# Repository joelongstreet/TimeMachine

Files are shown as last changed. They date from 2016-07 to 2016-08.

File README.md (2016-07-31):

# The Time Machine

An interactive hologram display.

## Hardware
Soldering several ICs was extremely cumbersome and time consuming, so I elected to design and print my own circuit boards.

### Schematic 
schematic

### Board Layout
board layout

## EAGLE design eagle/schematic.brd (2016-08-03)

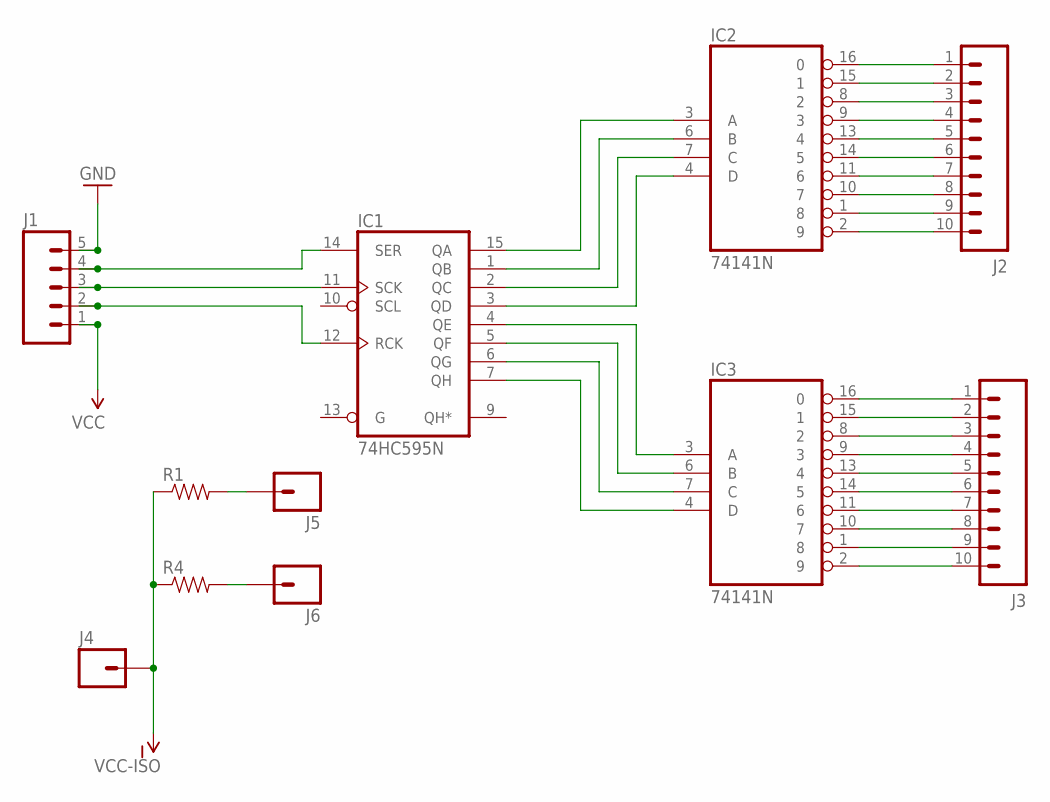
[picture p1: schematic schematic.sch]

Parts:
IC1: 74HC595N; DIL16
IC2, IC3: 74141N; DIL16
J1: M05LOCK; 1X05_LOCK
J2, J3: M10LOCK; 1X10_LOCK
J4, J5, J6: M01PTH; 1X01
R1, R4: RESISTORPTH-1/4W; AXIAL-0.4

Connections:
GND: IC1.8 (GND), IC2.12 (GND), IC3.12 (GND), J1.5
unnamed: IC1.15 (QA), IC2.3 (A)
unnamed: IC1.1 (QB), IC2.6 (B)
unnamed: IC1.2 (QC), IC2.7 (C)
unnamed: IC1.3 (QD), IC2.4 (D)
unnamed: IC1.4 (QE), IC3.3 (A)
unnamed: IC1.5 (QF), IC3.6 (B)
unnamed: IC1.6 (QG), IC3.7 (C)
unnamed: IC1.7 (QH), IC3.4 (D)
unnamed: IC2.16 (0), J2.1
unnamed: IC2.15 (1), J2.2
unnamed: IC2.8 (2), J2.3
unnamed: IC2.9 (3), J2.4
unnamed: IC2.13 (4), J2.5
unnamed: IC2.14 (5), J2.6
unnamed: IC2.11 (6), J2.7
unnamed: IC2.10 (7), J2.8
unnamed: IC2.1 (8), J2.9
unnamed: IC2.2 (9), J2.10
unnamed: IC3.16 (0), J3.1
unnamed: IC3.15 (1), J3.2
unnamed: IC3.8 (2), J3.3
unnamed: IC3.9 (3), J3.4
unnamed: IC3.13 (4), J3.5
unnamed: IC3.14 (5), J3.6
unnamed: IC3.11 (6), J3.7
unnamed: IC3.10 (7), J3.8
unnamed: IC3.1 (8), J3.9
unnamed: IC3.2 (9), J3.10
unnamed: J5.1, R1.P$2 (2)
unnamed: J6.1, R4.P$2 (2)
unnamed: IC1.14 (SER), J1.4
unnamed: IC1.11 (SCK), J1.3
unnamed: IC1.12 (RCK), J1.2
VCC: IC1.16 (VCC), IC2.5 (VCC), IC3.5 (VCC), J1.1
VCC-ISO: J4.1, R1.P$1 (1), R4.P$1 (1)

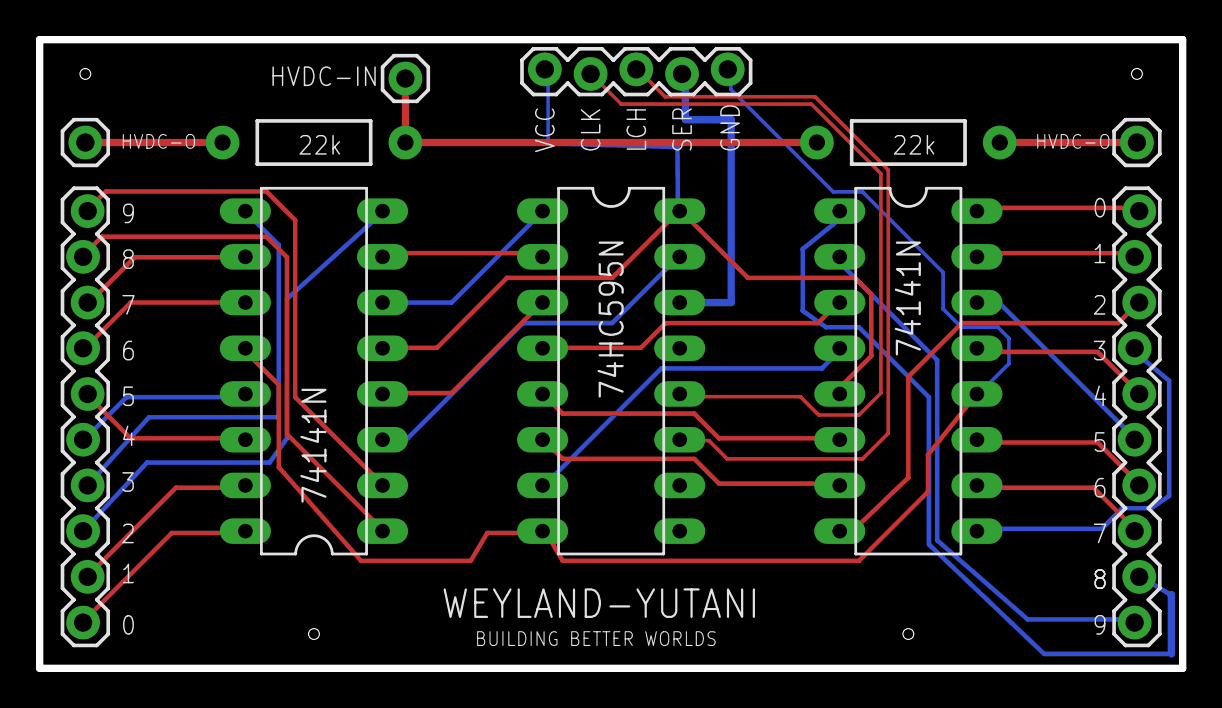
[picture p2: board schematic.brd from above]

Board: 2 copper layers, 63.5 x 34.9 mm, 11 parts (0 on the bottom side), 36 nets.

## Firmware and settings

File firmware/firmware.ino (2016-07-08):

// config
const int potLo   = 0;
const int potHi   = 725;
const int minYear = 1909;
const int maxYear = 2016;

// inputs
const int yearSelector        = A2;
const int registerA_latchPin  = 2;
const int registerA_clockPin  = 3;
const int registerA_dataPin   = 4;
const int registerB_latchPin  = 5;
const int registerB_clockPin  = 6;
const int registerB_dataPin   = 7;

// set a default year and retain
int year      = minYear;
int lastYear  = 0;

// create an array that translates decimal numbers into
// an appropriate byte for sending to the shift register
int byteConversionTable[] = {
  0,128,64,192,32,160,96,224,16,144,
  8,136,72,200,40,168,104,232,24,152,
  4,132,68,196,36,164,100,228,20,148,
  12,140,76,204,44,172,108,236,28,156,
  2,130,66,194,34,162,98,226, 18,146,
  10,138,74,202,42,170,106,234,26,154,
  6,134,70,198,38,166,102,230,22,150,
  14,142,78,206,46,174,110,238,30,158,
  1,129,65,193,33,161,97,225,17,145,
  9,137,73,201,41,169,105,233,25,153
 };


// setpu the serial device and potentiometer
void setup() {
  pinMode(yearSelector,       INPUT);
  pinMode(registerA_latchPin, OUTPUT);
  pinMode(registerA_clockPin, OUTPUT);
  pinMode(registerA_dataPin,  OUTPUT);
  pinMode(registerB_latchPin, OUTPUT);
  pinMode(registerB_clockPin, OUTPUT);
  pinMode(registerB_dataPin,  OUTPUT);

  Serial.begin(9600);
}



void loop() {
  // retrieve the potentiometer value
  int potValue = 0;
  potValue = analogRead(yearSelector);

  // map the potentiometer values to the year values 
  year = map(potValue, potLo, potHi, minYear, maxYear);
  if(year < 1909) year = 1909;
  if(year > 2016) year = 2016;

  if(lastYear != year){
    // update the nixie tubes
    updateShiftRegister();

    // broadcast the string to connected devices
    String yearString = String(year);
    Serial.print(yearString);

    // update
    lastYear = year;
  }
  
  // don't flood
  delay(100);
}


void updateShiftRegister(){
  // get the first 2 digits and update the A shift register
  int century = year/100;
  byte centuryByte = byteConversionTable[century];
  digitalWrite(registerA_latchPin, LOW);
  shiftOut(registerA_dataPin, registerA_clockPin, LSBFIRST, centuryByte);
  digitalWrite(registerA_latchPin, HIGH);

  // get the second 2 digits and update the B shift register
  int years = year - century*100;
  byte yearByte = byteConversionTable[years];
  digitalWrite(registerB_latchPin, LOW);
  shiftOut(registerB_dataPin, registerB_clockPin, LSBFIRST, yearByte);
  digitalWrite(registerB_latchPin, HIGH);
}

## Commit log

2016-07-08 hook up nixie tubes and display year on iDevice
2016-07-31 add links to schematic and board layout
2016-08-03 add eagle files
    [schematic.brd, schematic.sch]

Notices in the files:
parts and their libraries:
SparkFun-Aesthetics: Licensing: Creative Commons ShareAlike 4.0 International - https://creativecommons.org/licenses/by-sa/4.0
